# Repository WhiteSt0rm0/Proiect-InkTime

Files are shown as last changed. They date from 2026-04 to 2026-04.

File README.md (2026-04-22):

# Proiect InkTime

An affordable, open-source smartwatch powered by the nRF52840 with an e-paper display, designed for low power consumption and BLE connectivity.

## Table of Contents

1. [Hardware Diagram](#hardware-diagram)
2. [Bill of Materials](#bill-of-materials-bom)
3. [Hardware Description](#hardware-description)
4. [Pin Assignment](#nrf52840-pin-assignment)
5. [PCB Design Details](#pcb-design-details)

---

## Hardware Diagram

The InkTime smartwatch is built around the Nordic nRF52840 microcontroller and features the following subsystems:

```
                                    ┌───────────────────┐
                                    │    USB-C (J4)     │
                                    └──┬─────────────┬──┘
                                 VBUS  │             │ D+, D-
                                       │      ┌──────▼────────┐
                          ┌────────────┤      │  USBLC6 (D3)  │
                          │            │      │ ESD Protection│
                          │            │      └──────┬────────┘
                          │            │             │ D+, D- (protected)
                   ┌──────▼────────┐   │      ┌──────▼─────────────────────────┐
                   │  BQ25180 (IC3)│   │      │                                │
                   │  LiPo Charger │   │      │        nRF52840 (NRF52840_QF)  │
                   │  (I2C config) │   │      │        ARM Cortex-M4F @ 64MHz  │
                   └──────┬────────┘   │      │        BLE 5.0                 │
                          │            │      │                                │
                    VBAT  │     VBUS   │      │  ┌─────────────────────────┐   │
          ┌───────────────┤◄───────────┘      │  │ Interfaces:             │   │
          │               │                   │  │  SPI  → E-Paper Display │   │
   ┌──────▼────────┐      │                   │  │  I2C  → BMA423, DRV2605 │   │
   │ LiPo Battery  │      │                   │  │         MAX17048,       │   │
   │ LP502030      │      │                   │  │         BQ25180, RT6160 │   │
   │ 3.7V / 250mAh │      │                   │  │  USB  → USB-C (J4)      │   │
   └──────┬────────┘      │                   │  │  GPIO → Buttons, EPD    │   │
          │ VBAT          │                   │  │         ctrl, Haptic EN │   │
   ┌──────▼────────┐      │                   │  │  SWD  → TC2030 (J1)     │   │
   │ MAX17048 (U1) │──────│── I2C ───────────►│  └─────────────────────────┘   │
   │ Fuel Gauge    │      │                   │                                │
   │ (ALERT → GPIO)│      │                   │◄──── 32MHz Crystal (X1)        │
   └───────────────┘      │                   │◄──── 32.768kHz Crystal (X2)    │
                          │                   │◄──── 2.4GHz Antenna (ANT1)     │
                   ┌──────▼────────┐          │      via matching network      │
                   │  RT6160 (IC1) │          │      (L1, C3, C4, C9)          │
                   │  DC/DC        │          │                                │
                   │  Buck-Boost   │ VREG/3V3 │                                │
                   │  (I2C config) ├─────────►│                                │
                   └───────────────┘          └──┬──────┬──────┬───────────┬───┘
                                                 │      │      │           │
                              SPI (MOSI,SCK,CS)  │      │      │           │ GPIO
                              + GPIO ctrl        │      │ I2C  │ I2C       │ (SW_UP P0.26)
                                                 │      │      │           │ (SW_DN P0.27)
                  ┌──────────────────────┐       │      │      │       ┌───▼──────────────────┐
                  │  1.54" E-Paper (J2)  │◄──────┘      │      │       │  3×        Buttons   │
                  │  200×200px SPI       │              │      │       │  EVP-AKE31A          │
                  │                      │              │      │       │  (SW_ENT P1.00)      │
                  │  EPD Boost Circuit:  │              │      │       └──────────────────────┘
                  │  Q1 (DMG2305UX)      │              │      │
                  │  Q3 (SI1308EDL)      │       ┌──────▼──┐   │
                  │  D2,D4,D5 (MBR0530)  │       │ BMA423  │   │
                  │  L5 (68µH)           │       │  (IC2)  │   │
                  │  → PREVGH, PREVGL    │       │  IMU    │   │
                  └──────────────────────┘       └─────────┘   │
                                                        ┌──────▼──────┐
                           ┌──────────────┐             │  DRV2605    │
                           │  TC2030 (J1) │             │   (IC4)     │
                           │  SWD Debug   │             │  Haptic     │
                           │  (SWDIO,     │             │  Driver     │
                           │   SWDCLK,    │             │  + Motor    │
                           │   SWO, RST)  │             │  (FIT0774)  │
                           └──────────────┘             └─────────────┘
```

---

## Bill of Materials (BOM)

| Component | Value / Part Number | Package | Qty | Description | Datasheet |
|---|---|---|-----|---|---|
| NRF52840_QF | nRF52840 | QFN-73 | 1 | MCU with BLE 5.0 | [Link](datasheet-link) |
| IC1 | RT6160 | AWSCWL-CSP-15 | 1 | DC/DC Buck-Boost Converter | [Link](datasheet-link) |
| IC2 | BMA423 | LGA-12 | 1 | Triaxial Accelerometer (IMU) | [Link](datasheet-link) |
| IC3 | BQ25180 | YBGRDS-BGA-8 | 1 | LiPo Charger | [Link](datasheet-link) |
| IC4 | DRV2605 | YZFR-WCSP-9 | 1 | Haptic Driver | [Link](datasheet-link) |
| U1 | MAX17048 | G+T10-TDFN-8 | 1 | Fuel Gauge | [Link](datasheet-link) |
| D3 | USBLC6-2SC6Y | SOT-23-6 | 1 | ESD Protection | [Link](datasheet-link) |
| ANT1 | 2450AT18B100E | SMD | 1 | 2.4GHz Chip Antenna | [Link](datasheet-link) |
| X1 | 32MHz Crystal | SMD 2016 | 1 | Main Clock | - |
| X2 | 32.768kHz Crystal | SMD 3215 | 1 | RTC Clock | - |
| J1 | TC2030-IDC | Tag-Connect | 1 | SWD Debug Header | [Link](datasheet-link) |
| J2 | 503480-2400 | FPC-24 | 1 | E-Paper FPC Connector | [Link](datasheet-link) |
| J4 | KH-TYPE-C-16P | SMD | 1 | USB-C Connector | - |
| Q1 | DMG2305UX-7 | SOT-23 | 1 | P-Ch MOSFET (EPD drive) | [Link](datasheet-link) |
| Q3 | SI1308EDL-T1-GE3 | SC-70 | 1 | N-Ch MOSFET (EPD drive) | [Link](datasheet-link) |
| D2, D4, D5 | MBR0530 | SOD-123 | 3 | Schottky Diode (EPD drive) | - |
| L1 | 3.9nH | SMD 2012 | 1 | RF Matching Network | - |
| L2 | 10µH | SMD 2012 | 1 | nRF Power Inductor | - |
| L3 | 15nH | SMD 2012 | 1 | RF Filter | - |
| L5 | 68µH | SMD 2012 | 1 | EPD Boost Inductor | - |
| L7 | FTC252012SR47M-BCA | SMD 2012 | 1 | DC/DC Power Inductor (0.47µH) | - |
| SW_UP, SW_DN, SW_ENT | EVP-AKE31A | SMD | 3 | Tactile Buttons | - |
| SJ1 | Solder Jumper | SMD | 1 | Configuration Jumper | - |
| R1, R2, R5 | 0Ω | 0201 | 3 | Zero-ohm Resistors | - |
| R3, R4 | 3.3kΩ | 0201 | 2 | I2C Pull-up Resistors | - |
| R6, R2_EP_DR, R_PWR_EPD | 10kΩ | 0201 | 3 | Pull-up/Pull-down | - |
| R7, R8, R9 | 10kΩ | 0201 | 3 | Button Pull-down Resistors | - |
| R1_USB, R2_USB | 5.1kΩ | 0201 | 2 | USB-C CC Pull-down | - |
| R_TYPE_SEL | 2.2Ω | 0201 | 1 | EPD Type Select | - |
| R1_EP_DR | 0.47Ω | 0201 | 1 | EPD Current Sense | - |
| C1, C2, C17, C18 | 12pF | 0201 | 4 | Crystal Load Capacitors | - |
| C3, C4 | 1pF | 0201 | 2 | RF Matching | - |
| C9 | 820pF | 0201 | 1 | RF Matching | - |
| C5, C7, C8, C12, C19 | 100nF | 0201 | 5 | Decoupling Capacitors | - |
| C11 | 100pF | 0201 | 1 | Decoupling (DEC5) | - |
| C16 | 47nF | 0201 | 1 | Decoupling | - |
| C15 | 1.0µF | 0402 | 1 | Decoupling | - |
| C6, C14, C20, C21, C43, C2_EP_DR | 4.7µF | 0402 | 6 | Bulk Capacitors | - |
| C24, C39, C1_EP_DR | 10µF | 0402 | 3 | Input/Output Caps | - |
| C25, C33 | 22µF | 0402 | 2 | DC/DC Output Caps | - |
| C23, C27, C34, C42, EPD_C5 | 0.1µF | 0201 | 5 | Decoupling | - |
| C29-C32, C37, C38, EPD_C1-C12 | 1µF | 0402 | 15 | Filter/Bypass Caps | - |
| C10, C13, C22 | N.C. | 0201 | 3 | Do Not Populate | - |
| Test Pads | - | SMD | 14 | TP_GND, TP_3V3, TP_VBAT, etc. | - |

---

## Hardware Description

### Microcontroller — nRF52840 (NRF52840_QF)

The nRF52840 is the core of the InkTime, providing Bluetooth Low Energy 5.0 connectivity, ARM Cortex-M4F processing at 64MHz, and extensive GPIO. It communicates with peripherals via I2C and SPI buses and is powered by 3.3V from the RT6160 DC/DC converter.

Two crystals provide clock sources: a 32MHz crystal (X1) connected to XC1/XC2 with 12pF load capacitors (C1, C2), and a 32.768kHz crystal (X2) connected to P0.00/XL1 and P0.01/XL2 with 12pF load capacitors (C17, C18).

The RF section uses a 2450AT18B100E chip antenna connected through an impedance matching network (L1=3.9nH, C3=1pF, C4=1pF, C9=820pF) to the ANT pin. The antenna is placed at the edge of the PCB with a copper keepout zone on all layers underneath.

Decoupling capacitors placed close to corresponding power pins: C5 (100nF) on DEC1, C8 (100nF) on DEC3, C7 (100nF) on DEC4_6, C11 (100pF) on DEC5, C15 (1.0µF). Capacitors C10, C13, C22 are N.C. (Do Not Populate) per Nordic's reference design.

### Power Management

**LiPo Charger — BQ25180 (IC3):** Manages battery charging from USB-C (VBUS). Single-cell LiPo battery connected directly to test pads (TP_VBAT, TP_BAT_GND). I2C configurable. Interrupt output (PMIC_INT) to nRF52840. Bypass capacitors C37 (1µF), C39 (10µF). Pull-up R6 (10kΩ) on TS/MR.

**DC/DC Converter — RT6160 (IC1):** Buck-boost converter, VBAT (3.0–4.2V) to VREG/3V3. I2C voltage selection via VSEL pin. Power inductor L7 (0.47µH). Input cap C23 (0.1µF), output caps C24 (10µF), C25 (22µF), C33 (22µF). I2C pull-ups R3, R4 (3.3kΩ).

**Fuel Gauge — MAX17048 (U1):** Battery monitoring via I2C. CELL pin to VBAT, ALERT output to nRF52840. Bypass cap C38 (1µF).

### Display — 1.54" E-Paper

Connected via J2 (503480-2400). Uses an SPI interface (MOSI, SCK, EPD_CS). The drive circuit features Q3 (SI1308EDL), Q1 (DMG2305UX), diodes D2/D4/D5 (MBR0530), inductor L5 (68µH), and capacitors EPD_C1–C12 for high-voltage generation (PREVGH, PREVGL). Control signals include EPD_RST, EPD_BUSY, and EPD_DC.

### IMU — BMA423 (IC2)

Triaxial accelerometer connected via I2C (SDA, SCL). Provides two interrupt outputs (IMU_INT1, IMU_INT2) for motion/step/gesture detection. Features a decoupling C19 (100nF) and zero-ohm resistors R1, R2, R5 for pin configuration.

### Haptic Driver — DRV2605 (IC4)

I2C haptic driver for the vibration motor (FIT0774). Enabled via the HAPTIC_EN GPIO pin. Includes decoupling capacitors C32 (1µF) and C34 (0.1µF).

### USB-C and ESD Protection

Features a KH-TYPE-C-16P connector (J4) with USBLC6-2SC6Y (D3) for ESD protection. Includes CC pull-downs R1_USB, R2_USB (5.1kΩ) and bypass caps C42 (0.1µF), C43 (4.7µF).

### SWD Debug — TC2030-IDC (J1)

Utilizes a Tag-Connect pogo-pin interface: SWDIO, SWDCLK, SWO, RESET, 3.3V, GND. This allows for debugging without requiring a permanent connector on the board.

---

## nRF52840 Pin Assignment

| Pin | Signal | Function | Interface |
|-----|---|---|---|
| P0.00/XL1 | XL1 | 32.768kHz Crystal | Clock |
| P0.01/XL2 | XL2 | 32.768kHz Crystal | Clock |
| P0.04/AIN2 | IMU_INT1 | BMA423 Interrupt 1 | GPIO |
| P0.05/AIN3 | IMU_INT2 | BMA423 Interrupt 2 | GPIO |
| P0.06 | EPD_CS | E-Paper Chip Select | SPI |
| P0.07 | EPD_DC | E-Paper Data/Command | GPIO |
| P0.08 | EPD_RST | E-Paper Reset | GPIO |
| P0.09/NFC1 | PMIC_INT | BQ25180 Interrupt | GPIO |
| P0.11 | SCK | SPI Clock (E-Paper) | SPI |
| P0.12 | MOSI | SPI Data (E-Paper) | SPI |
| P0.13 | EPD_BUSY | E-Paper Busy | GPIO |
| P0.14 | SCL | I2C Clock | I2C |
| P0.15 | SDA | I2C Data | I2C |
| P0.18/RESET | RESET | System Reset | Reset |
| P0.19 | HAPTIC_EN | DRV2605 Enable | GPIO |
| P0.26 | SW_UP | Button Up | GPIO |
| P0.27 | SW_DN | Button Down | GPIO |
| P1.00 | SW_ENT | Button Enter | GPIO |
| P1.01 | ALERT | MAX17048 Alert | GPIO |
| P1.09 | SWO | Debug Trace Output | Debug |
| XC1/XC2 | Crystal | 32MHz Oscillator | Clock |
| ANT | RF | Antenna via matching | RF |
| VBUS | USB_VBUS | USB Power (5V) | Power |
| D+/D- | USB Data | USB Data Lines | USB |
| SWDIO | Debug | SWD Data | Debug |
| SWDCLK | Debug | SWD Clock | Debug |

**Note:** The I2C Bus is shared by BMA423 (IC2), BQ25180 (IC3), RT6160 (IC1), DRV2605 (IC4), and MAX17048 (U1). It uses pull-ups R3, R4 (3.3kΩ) to 3V3.

---

## PCB Design Details

### Board Specifications

- **Dimensions:** 46mm × 35mm, rounded corners
- **Layers:** 4 (Top, Route2, Route63, Bottom)
- **Thickness:** 1.0mm
- **Trace widths:** 0.15mm (signals), 0.3mm (power)
- **Components:** All mounted on the TOP layer

### Layer Stack

| Layer | Name | Function |
|---|---|---|
| 1 | Top | Signals + GND polygon |
| 2 | Route2 | Dedicated GND plane |
| 6 | Route63 | Signal routing |
| 4 | Bottom | Signals + GND polygon |

### Design Decisions and Accepted Errors

**Copper Width Errors:** Power nets (3V3, VREG, VBAT, VBUS, etc.) require 0.3mm trace width per design rules. However, in dense areas—particularly around small IC packages and tight pad spacing—there is not enough physical space to maintain this width. These resulting DRC errors were manually verified and accepted.

**Copper Clearance Errors:** In highly congested areas (around the nRF52840 BGA and passive component clusters), some traces and pads violate the 0.15mm clearance rule. These occur where component placement leaves no alternative routing path and were accepted after confirming no actual shorts exist.

**Overlapping / Polygon Clearance Errors:** Some GND polygons on different layers generate clearance warnings where they overlap. These are non-functional warnings, as the polygons belong to the same net (GND).

**Board Outline Clearance Errors:** The three tactile buttons (SW_UP, SW_DN, SW_ENT) and the USB-C connector (J4) intentionally extend beyond the PCB edge for mechanical alignment with the enclosure cutouts. This is by design.

**N.C. Capacitors:** Footprints (C10, C13, C22) are present but intentionally not populated per Nordic's reference design.

**Silkscreen:** Proper labeling is applied to ICs, connectors, test pads, and capacitors.

**Via Stitching:** GND vias are distributed across the board between all ground planes, with a higher concentration around the nRF52840 and RF antenna area to ensure low-impedance ground return paths at 2.4GHz.

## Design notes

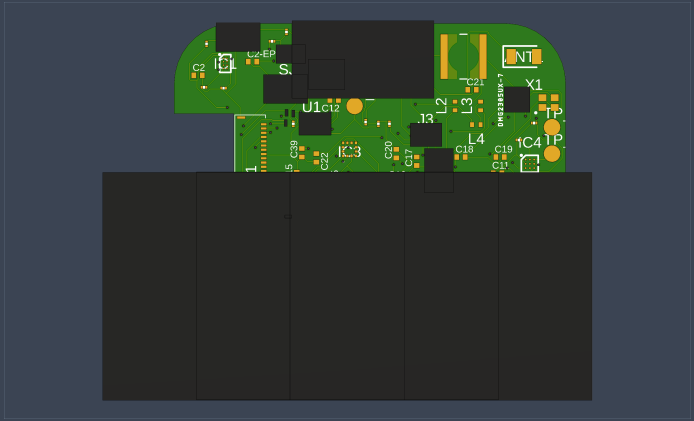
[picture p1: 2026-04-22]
Images/Screenshot 2026-04-22 132725.png

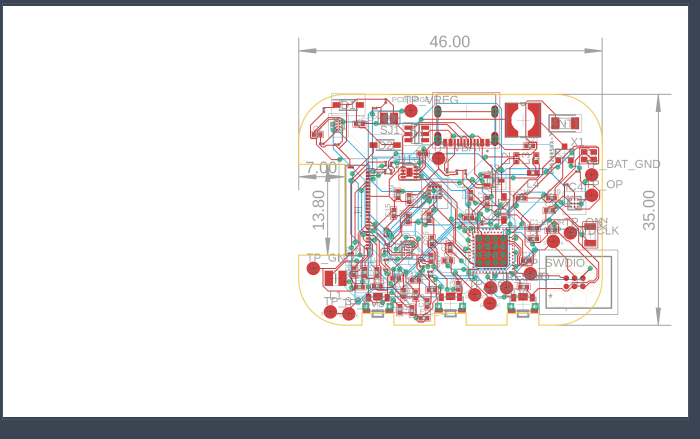
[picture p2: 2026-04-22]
Images/Screenshot 2026-04-22 132748.png

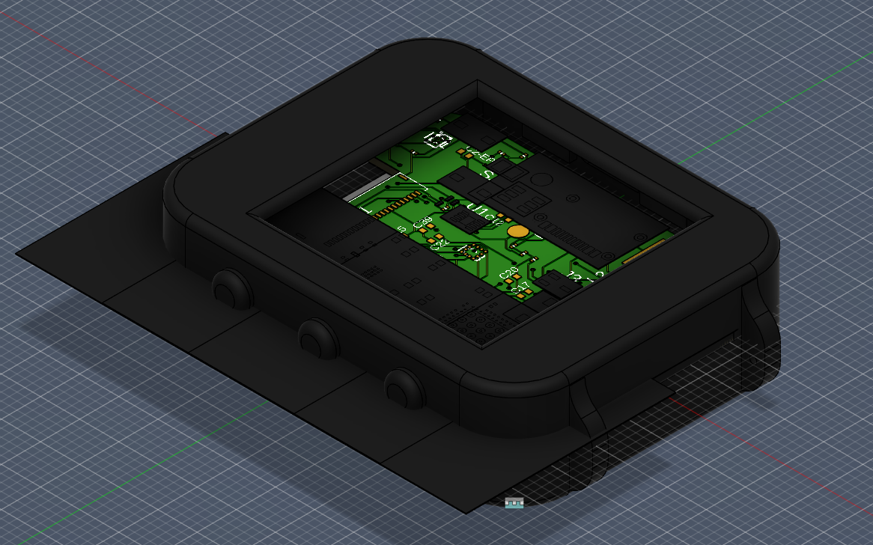
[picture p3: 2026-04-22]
Images/Screenshot 2026-04-22 132715.png

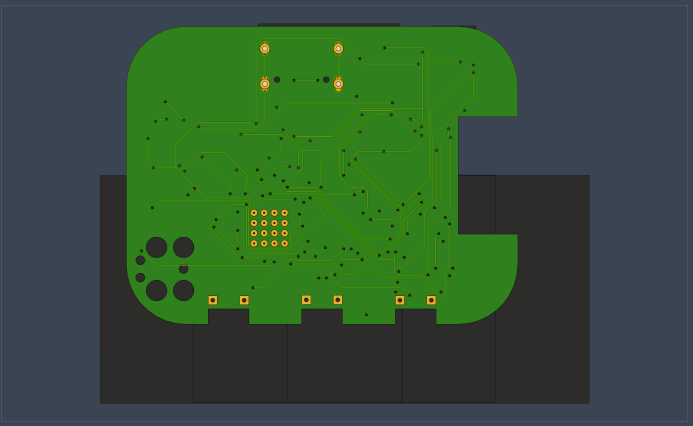
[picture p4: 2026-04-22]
Images/Screenshot 2026-04-22 132744.png

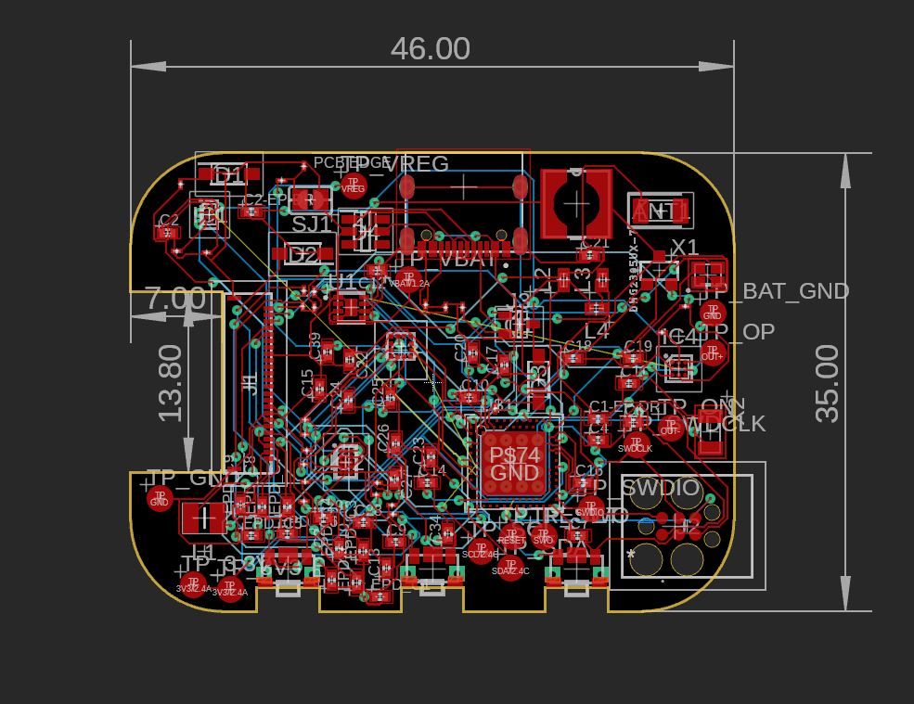
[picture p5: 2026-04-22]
Images/Screenshot 2026-04-22 132706.png

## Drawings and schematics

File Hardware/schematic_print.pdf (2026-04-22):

# LiPo Charger

# DC/DC

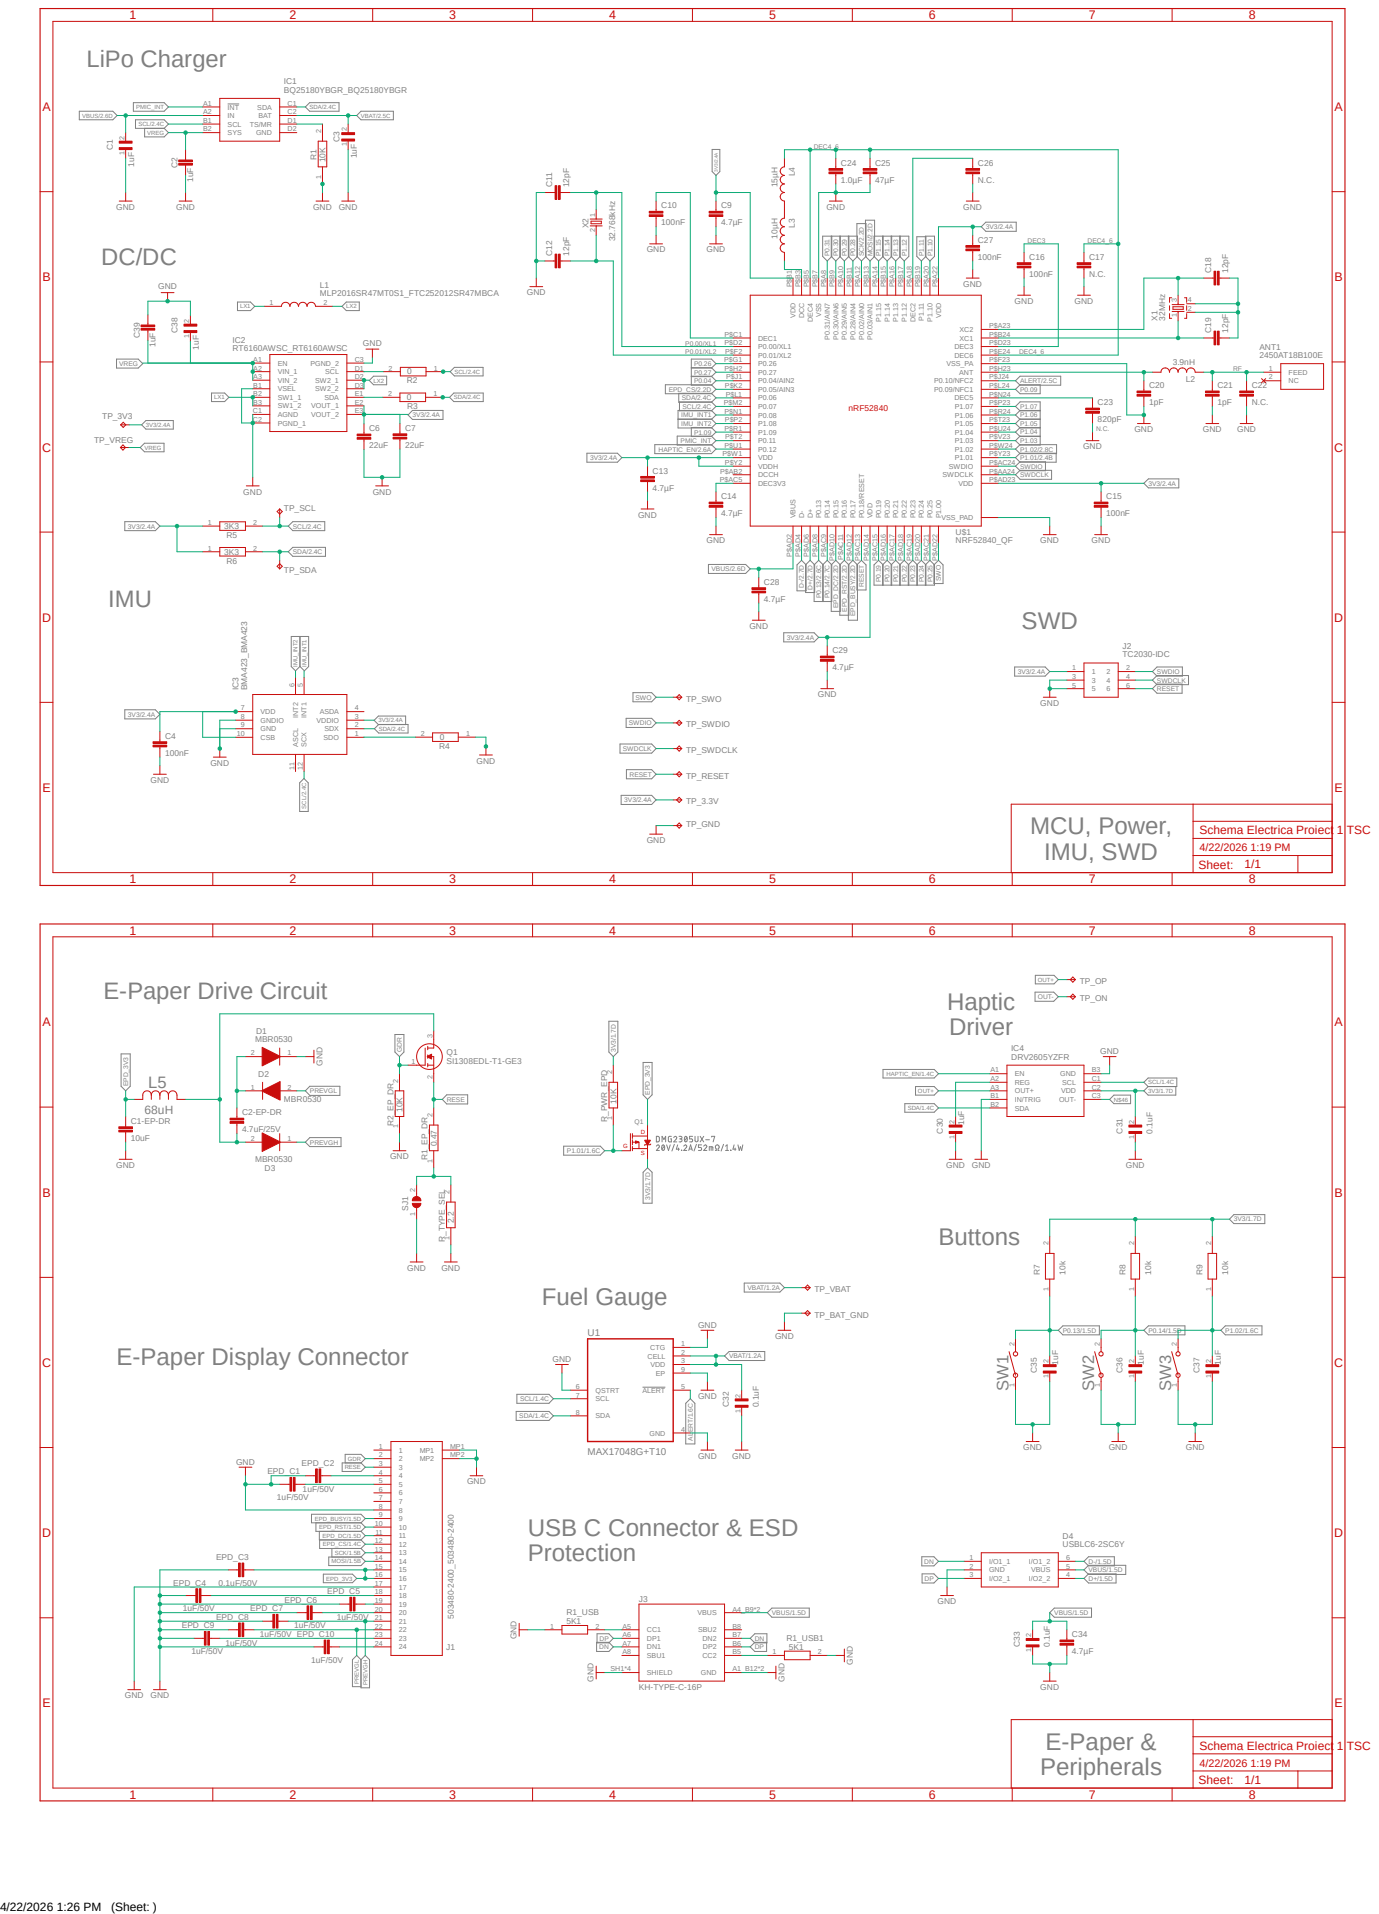
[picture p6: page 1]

MCU, Power, IMU, SWD

Schema Electrica Proiect 1 TSC

Sheet: 1/1

EPD_C5 | 18 18

EPD_C6 | 19 19

EPD_C8 | 1uF/50V | 21 21

EPD_C9 | 1uF/50V | | 22 22

E-Paper & Peripherals

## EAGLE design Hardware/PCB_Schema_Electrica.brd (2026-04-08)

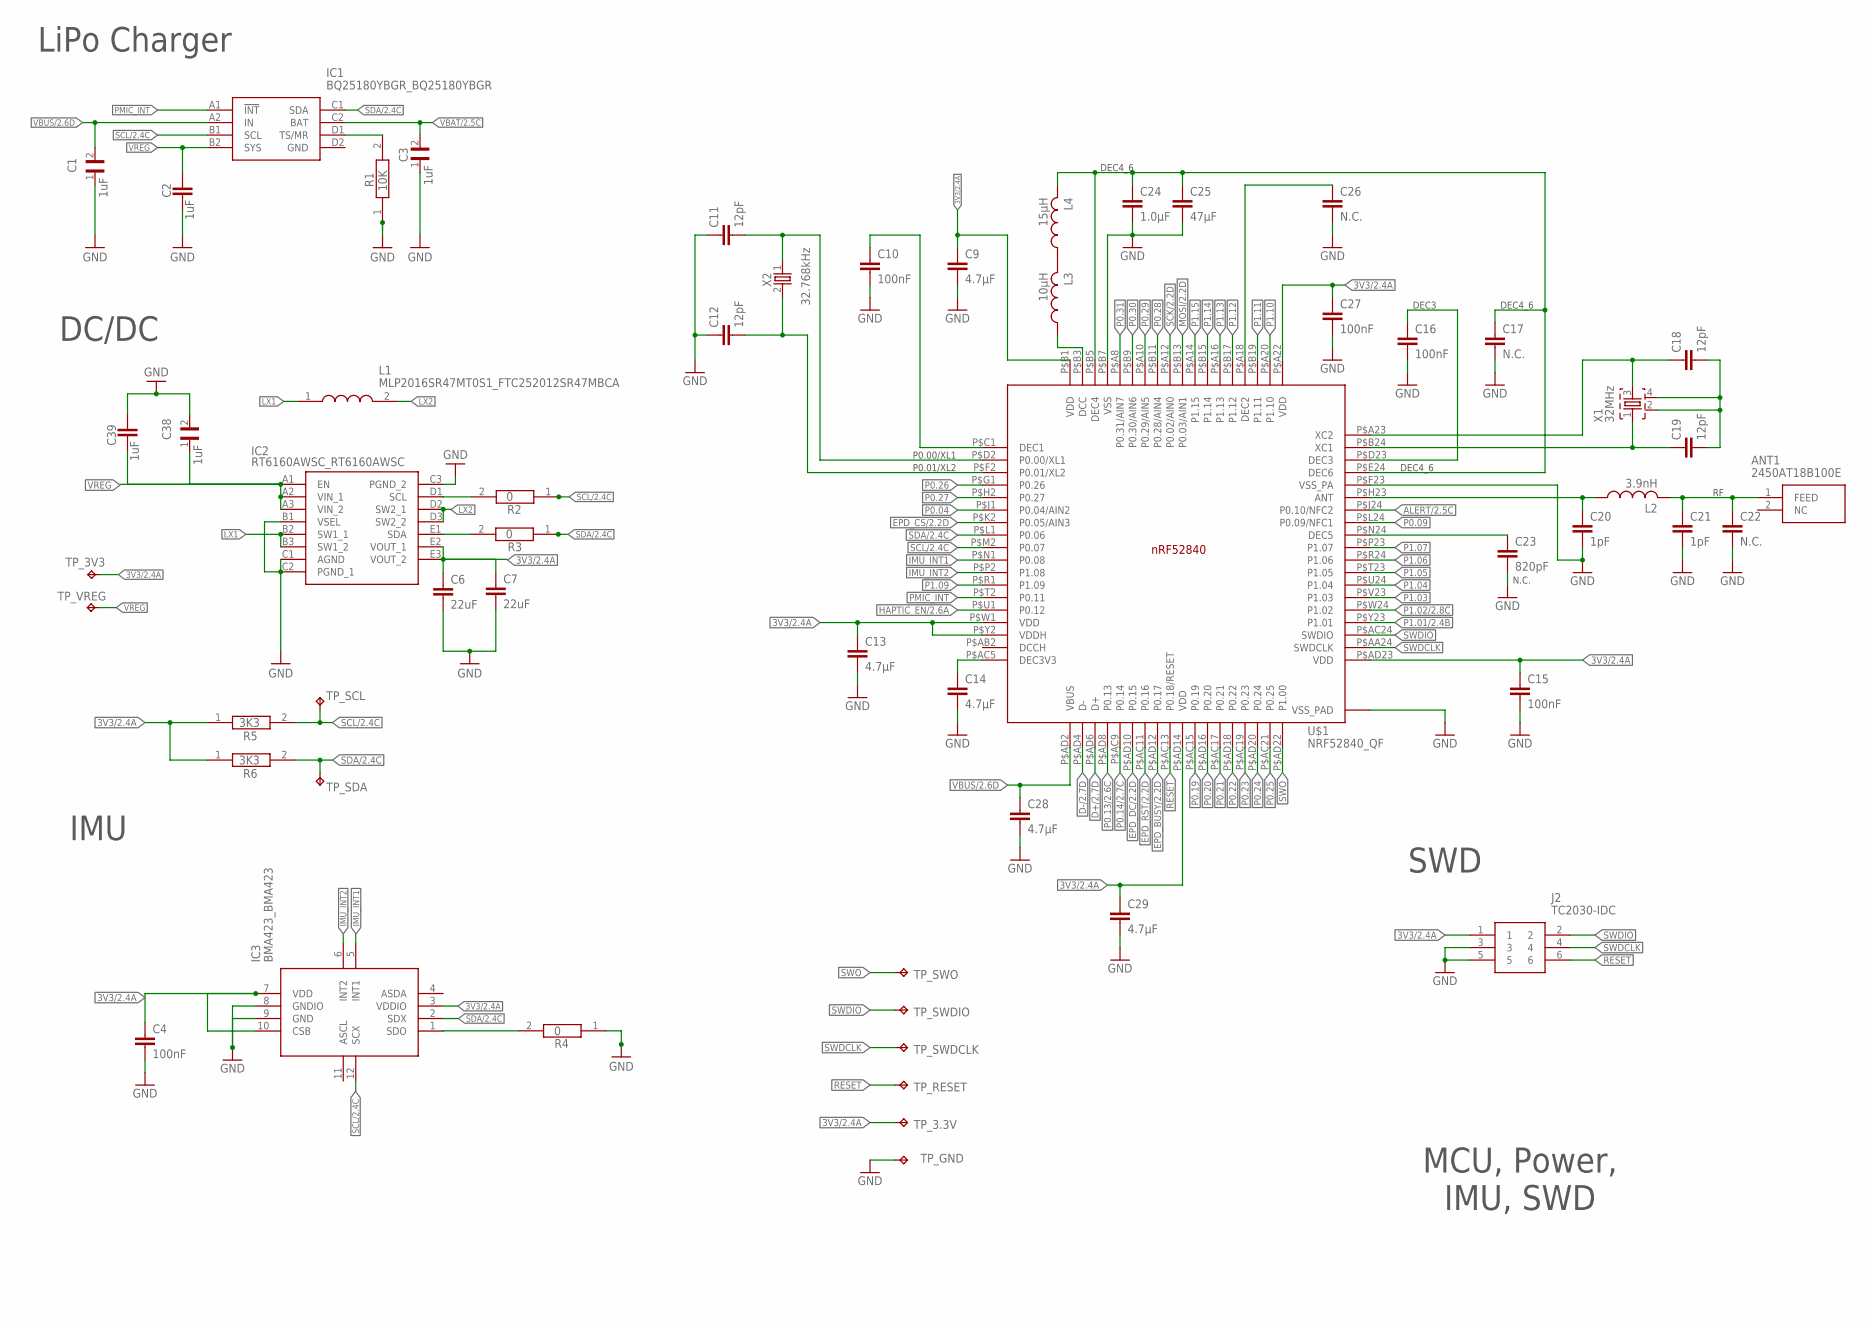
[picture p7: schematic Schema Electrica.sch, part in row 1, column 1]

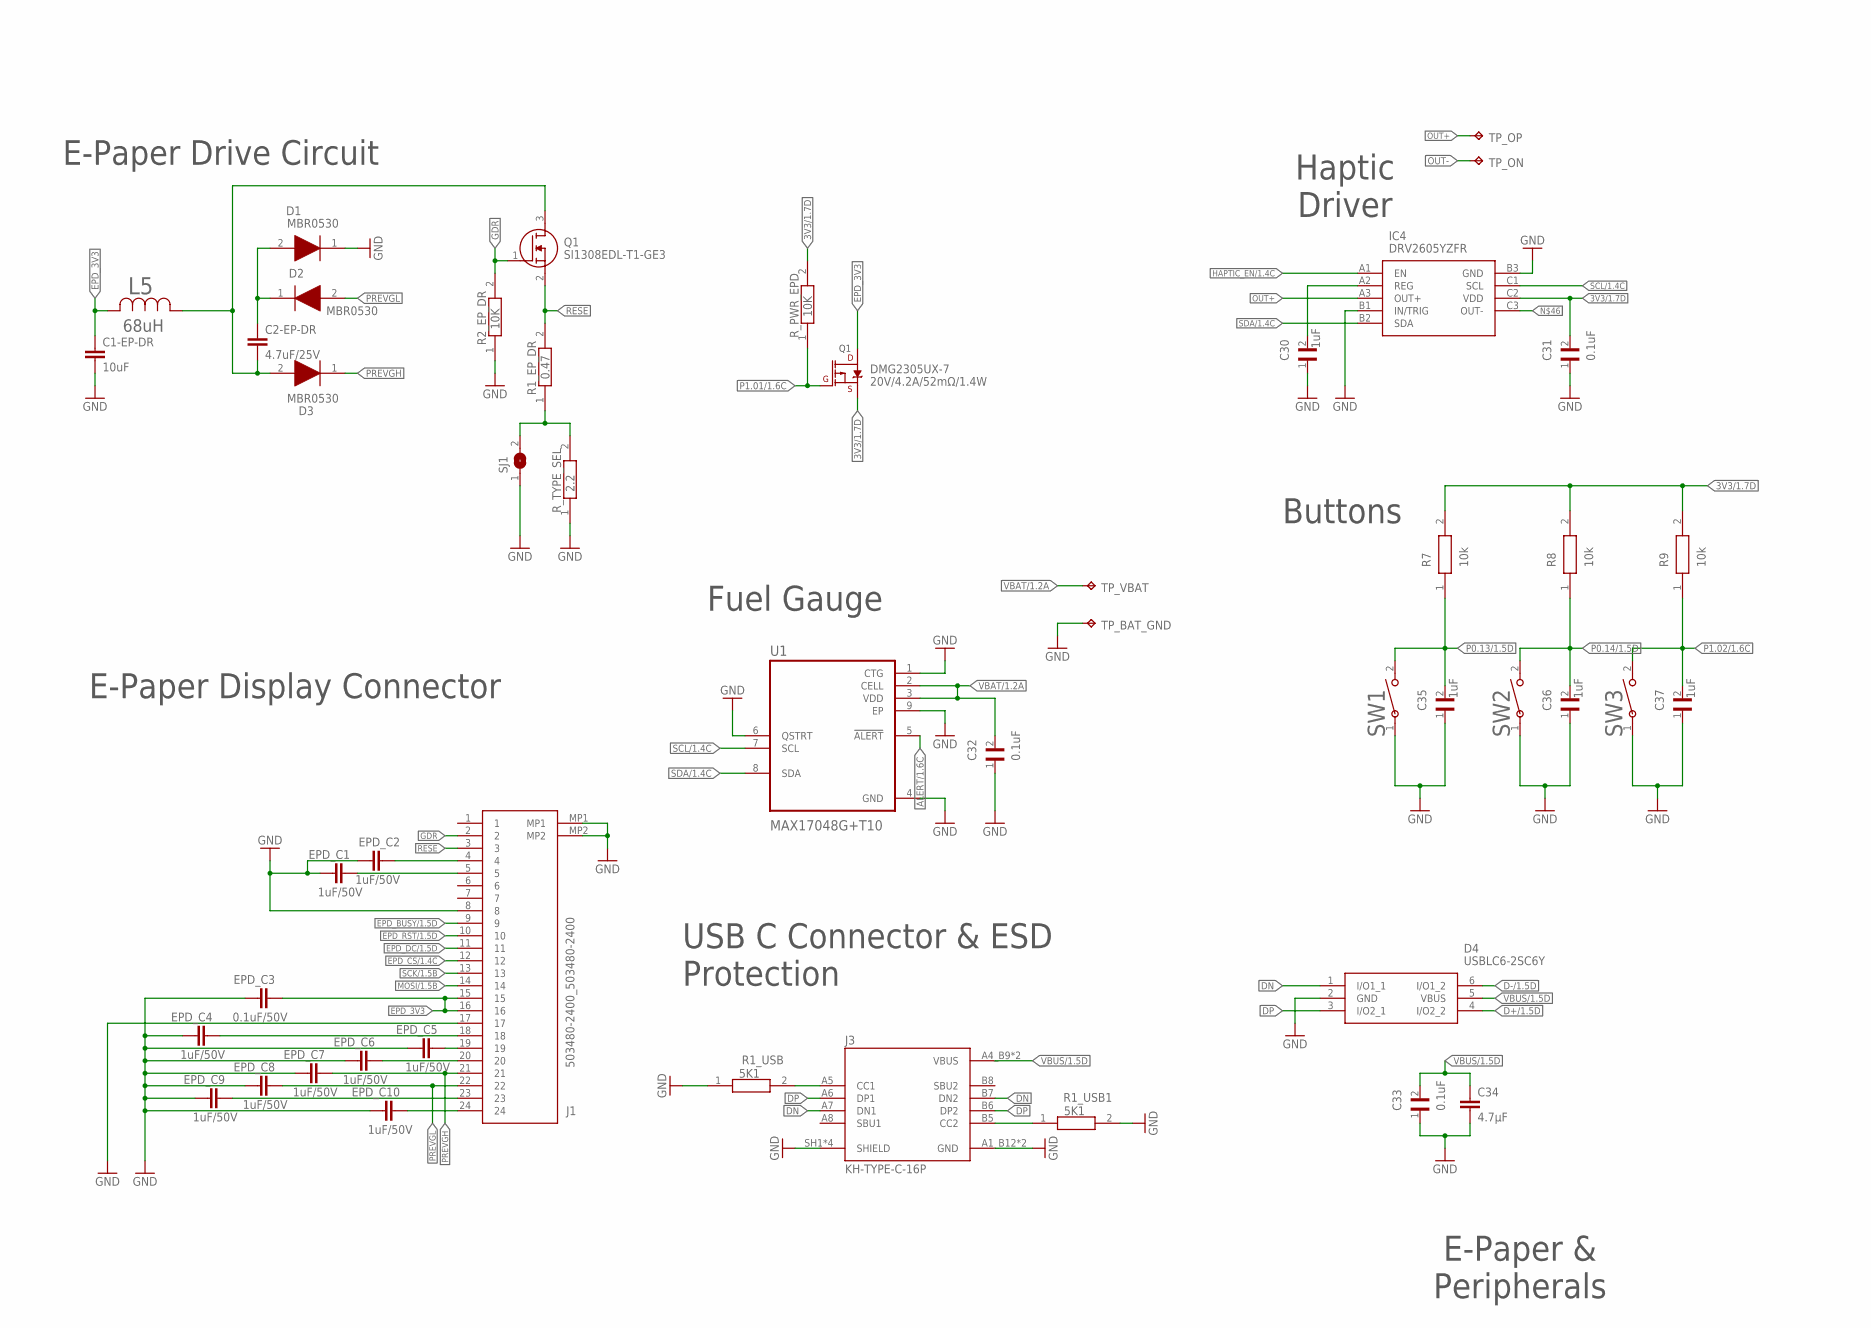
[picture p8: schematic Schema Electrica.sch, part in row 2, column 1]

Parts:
ANT1: 2450AT18B100E; 2450AT18B100E_ANTC3216X140N
C1, C3, C30, C35, C36, C37, C38: 1uF; GRM011R60J152KE01L_1_0201
C1-EP-DR: 10uF; PERFECT_0402_0402
C2, C39: 1uF; PERFECT_0402_0402
C2-EP-DR: 4.7uF/25V; PERFECT_0402_0402
C4, C10, C15, C16, C27: 100nF; PERFECT_0402_0402
C6, C7: 22uF; PERFECT_0402_0402
C9, C13, C14, C28, C29, C34: 4.7µF; PERFECT_0402_0402
C11, C12, C18, C19: 12pF; PERFECT_0402_0402
C17, C22, C26: N.C.; PERFECT_0402_0402
C20, C21: 1pF; PERFECT_0402_0402
C23: 820pF; PERFECT_0402_0402
C24: 1.0µF; PERFECT_0402_0402
C25: 47µF; PERFECT_0402_0402
C31, C32, C33: 0.1uF; GRM011R60J152KE01L_1_0201
D1, D2, D3: MBR0530; ESP32_C6_LIBRARY_5_SOD3716X135N
D4: USBLC6-2SC6Y; ESP32_C6_LIBRARY_3_SOT95P280X145-6N
DMG2305UX-7: 20V/4.2A/52mΩ/1.4W; ESP32_C6_LIBRARY_4_ESP32_C6_LIBRARY_4_ESP32_C6_LIBRARY_4_ES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
EPD_C1, EPD_C2, EPD_C4, EPD_C5, EPD_C6, EPD_C7, EPD_C8, EPD_C9, EPD_C10: 1uF/50V; PERFECT_0402_0402
EPD_C3: 0.1uF/50V; PERFECT_0402_0402
IC1: BQ25180YBGR_BQ25180YBGR; BQ25180YBGR_BGA8C40P2X4_100X155X50
IC2: RT6160AWSC_RT6160AWSC; RT6160AWSC_BGA15C40P3X5_140X230X60
IC3: BMA423_BMA423
IC4: DRV2605YZFR; DRV2605YZFR_BGA9C50P3X3_144X144X62
J1: 503480-2400_503480-2400; 503480-2400_5034802400
J2: TC2030-IDC; TC2030-IDC_TC2030IDC
J3: KH-TYPE-C-16P; KH-TYPE-C-16P_KINGHELM_KH-TYPE-C-16P
L1: MLP2016SR47MT0S1_FTC252012SR47MBCA; MLP2016SR47MT0S1_INDC2016X100N
L2: 3.9nH; NORDIC_NRF_2_RESC0402_L
L3: 10µH; NORDIC_NRF_2_RESC0402_L
L4: 15µH; NORDIC_NRF_2_RESC0402_L
L5: 68uH; ESP32_C6_LIBRARY_2_IND_4828-WE-TPC_WRE
Q1: SI1308EDL-T1-GE3; ESP32_C6_LIBRARY_6_SOT65P210X110-3N
R1, R2_EP_DR: 10K; CPF0201D7K68C1_0201
R1_EP_DR: 0.47; CPF0201D7K68C1_0201
R1_USB, R1_USB1: 5K1; CPF0201D7K68C1_0201
R2, R3: 0; CPF0201D7K68C1_0201
R4: 0; ERA-1AEB3401C_0201
R5, R6: 3K3; CPF0201D7K68C1_0201
R7, R8, R9: 10k; ERA-1AEB3401C_0201
R_PWR_EPD: 10K; CPF0201D7K68C1_0201
R_TYPE_SEL: 2.2; CPF0201D7K68C1_0201
SJ1: ESP32_C6_LIBRARY_7_JUMPER_SJ
SW1, SW2, SW3: 2025-10-22_07-23-44_LIBRARY_EVP-AKE31ASW_EVP-AKE3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; 2025-10-22_07-23-44_LIBRARY_SW_EVP-AKE31A_PAN
TP_3.3V, TP_3V3: HECTOR_WATCH_1_TPTP20R; HECTOR_WATCH_1_TP20R
TP_BAT_GND: HECTOR_WATCH_1_TPTP20R; HECTOR_WATCH_1_TP20R
TP_GND: HECTOR_WATCH_1_TPTP20R; HECTOR_WATCH_1_TP20R
TP_ON: HECTOR_WATCH_1_TPTP20R; HECTOR_WATCH_1_TP20R
TP_OP: HECTOR_WATCH_1_TPTP20R; HECTOR_WATCH_1_TP20R
TP_RESET: HECTOR_WATCH_1_TPTP20R; HECTOR_WATCH_1_TP20R
TP_SCL: HECTOR_WATCH_1_TPTP20R; HECTOR_WATCH_1_TP20R
TP_SDA: HECTOR_WATCH_1_TPTP20R; HECTOR_WATCH_1_TP20R
TP_SWDCLK: HECTOR_WATCH_1_TPTP20R; HECTOR_WATCH_1_TP20R
TP_SWDIO: HECTOR_WATCH_1_TPTP20R; HECTOR_WATCH_1_TP20R
TP_SWO: HECTOR_WATCH_1_TPTP20R; HECTOR_WATCH_1_TP20R
TP_VBAT: HECTOR_WATCH_1_TPTP20R; HECTOR_WATCH_1_TP20R
TP_VREG: HECTOR_WATCH_1_TPTP20R; HECTOR_WATCH_1_TP20R
U1: MAX17048G+T10; ESP32_C6_LIBRARY_SON50P200X200X80-9N
U$1: NRF52840_QF; NORDIC_NRF_4_AQFN50P700X700X85_HS-74N
X1: 32MHz; NORDIC_NRF_BT-XTAL_2016_N
X2: 32.768kHz; NORDIC_NRF_1_XTAL_3215_N

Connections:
3V3/1.7D: C31.2, DMG2305UX-7.2 (S), IC4.C2 (VDD), R7.2, R8.2, R9.2, R_PWR_EPD.2
3V3/2.4A: C4.1, C6.1, C7.1, C9.1, C13.1, C15.1, C27.1, C29.1, IC2.E2 (VOUT_1), IC2.E3 (VOUT_2), IC3.3 (VDDIO), IC3.7 (VDD), IC3.10 (CSB), J2.1, R5.1, R6.1, TP_3.3V.TP, TP_3V3.TP, U$1.P$A22 (VDD), U$1.P$AD14 (VDD), U$1.P$AD23 (VDD), U$1.P$B1 (VDD), U$1.P$W1 (VDD), U$1.P$Y2 (VDDH)
ALERT/1.6C: U1.5 (!ALERT)
ALERT/2.5C: U$1.P$J24 (P0.10/NFC2)
D+/1.5D: D4.4 (I/O2_2)
D+/2.7D: U$1.P$AD6 (D+)
D-/1.5D: D4.6 (I/O1_2)
D-/2.7D: U$1.P$AD4 (D-)
DEC3: C16.1, U$1.P$D23 (DEC3)
DN: D4.1 (I/O1_1), J3.A7 (DN1), J3.B7 (DN2)
DP: D4.3 (I/O2_1), J3.A6 (DP1), J3.B6 (DP2)
EPD_3V3: C1-EP-DR.1, DMG2305UX-7.3 (D), EPD_C3.2, J1.15, J1.16, L5.2
EPD_BUSY/1.5D: J1.9
EPD_BUSY/2.2D: U$1.P$AD12 (P0.17)
EPD_CS/1.4C: J1.12
EPD_CS/2.2D: U$1.P$K2 (P0.05/AIN3)
EPD_DC/1.5D: J1.11
EPD_DC/2.2D: U$1.P$AD10 (P0.15)
EPD_RST/1.5D: J1.10
EPD_RST/2.2D: U$1.P$AC11 (P0.16)
GDR: J1.2, Q1.1 (G), R2_EP_DR.2
GND: C1.1, C1-EP-DR.2, C2.2, C3.1, C4.2, C6.2, C7.2, C9.2, C10.2, C11.1, C12.1, C13.2, C14.2, C15.2, C16.2, C17.2, C20.2, C21.2, C22.2, C23.2, C24.2, C25.2, C26.2, C27.2, C28.2, C29.2, C30.1, C31.1, C32.1, C33.1, C34.2, C35.1, C36.1, C37.1, C38.2, C39.1, D1.1 (K), D4.2 (GND), EPD_C1.1, EPD_C2.1, EPD_C3.1, EPD_C4.1, EPD_C5.1, EPD_C6.1, EPD_C7.1, EPD_C8.1, EPD_C9.1, EPD_C10.1, IC3.8 (GNDIO), IC3.9 (GND), IC4.B1 (IN/TRIG), IC4.B3 (GND), J1.8, J1.17, J1.MP1, J1.MP2, J2.3, J2.5, J3.A1_B12 (GND), J3.A12_B1 (GND), J3.SH1 (SHIELD), J3.SH2 (SHIELD), J3.SH3 (SHIELD), J3.SH4 (SHIELD), R1.1, R1_USB.1, R1_USB1.2, R2_EP_DR.1, R4.1, R_TYPE_SEL.1, SJ1.1, SW1.1, SW2.1, SW3.1, TP_BAT_GND.TP, TP_GND.TP, U1.1 (CTG), U1.4 (GND), U1.6 (QSTRT), U1.9 (EP), U$1.P$74 (VSS_PAD), U$1.P$75 (VSS_PAD), U$1.P$76 (VSS_PAD), U$1.P$77 (VSS_PAD), U$1.P$78 (VSS_PAD), U$1.P$79 (VSS_PAD), U$1.P$80 (VSS_PAD), U$1.P$81 (VSS_PAD), U$1.P$82 (VSS_PAD), U$1.P$83 (VSS_PAD), U$1.P$84 (VSS_PAD), U$1.P$85 (VSS_PAD), U$1.P$86 (VSS_PAD), U$1.P$87 (VSS_PAD), U$1.P$88 (VSS_PAD), U$1.P$89 (VSS_PAD), U$1.P$90 (VSS_PAD), U$1.P$B7 (VSS), U$1.P$F23 (VSS_PA)
HAPTIC_EN/1.4C: IC4.A1 (EN)
HAPTIC_EN/2.6A: U$1.P$U1 (P0.12)
IMU_INT1: IC3.5 (INT1), U$1.P$N1 (P0.08)
IMU_INT2: IC3.6 (INT2), U$1.P$P2 (P1.08)
LX1: IC2.B2 (SW1_1), IC2.B3 (SW1_2), L1.1
LX2: IC2.D2 (SW2_1), IC2.D3 (SW2_2), L1.2
MOSI/1.5B: J1.14
MOSI/2.2D: U$1.P$B13 (P0.03/AIN1)
unnamed: IC1.D1 (TS/MR), R1.2
unnamed: IC2.D1 (SCL), R2.2
unnamed: IC2.E1 (SDA), R3.2
unnamed: IC3.1 (SDO), R4.2
unnamed: IC2.B1 (VSEL), IC2.C1 (AGND), IC2.C2 (PGND_1)
unnamed: C10.1, U$1.P$C1 (DEC1)
unnamed: C11.2, U$1.P$D2 (P0.00/XL1), X2.1
unnamed: C12.2, U$1.P$F2 (P0.01/XL2), X2.2
unnamed: C14.1, U$1.P$AC5 (DEC3V3)
unnamed: C17.1, C24.1, C25.1, L4.2, U$1.P$B5 (DEC4), U$1.P$E24 (DEC6)
unnamed: C18.1, U$1.P$A23 (XC2), X1.3
unnamed: C18.2, C19.2, X1.2, X1.4
unnamed: C19.1, U$1.P$B24 (XC1), X1.1
unnamed: C20.1, L2.1, U$1.P$H23 (ANT)
unnamed: ANT1.1 (FEED), C21.1, C22.1, L2.2
unnamed: C23.1, U$1.P$N24 (DEC5)
unnamed: L3.1, U$1.P$B3 (DCC)
unnamed: C26.1, U$1.P$A18 (DEC2)
unnamed: L3.2, L4.1
unnamed: C2-EP-DR.1, D1.2 (A), D2.1 (K)
unnamed: C2-EP-DR.2, D3.2 (A), L5.1, Q1.3 (D)
unnamed: EPD_C2.2, J1.4
unnamed: EPD_C1.2, J1.5
unnamed: EPD_C4.2, J1.18
unnamed: EPD_C5.2, J1.19
unnamed: EPD_C6.2, J1.20
unnamed: J3.A5 (CC1), R1_USB.2
unnamed: R1_EP_DR.1, R_TYPE_SEL.2, SJ1.2
unnamed: EPD_C9.2, J1.23
unnamed: EPD_C10.2, J1.24
unnamed: C30.2, IC4.A2 (REG)
unnamed: J3.B5 (CC2), R1_USB1.1
OUT+: IC4.A3 (OUT+), TP_OP.TP
OUT-: TP_ON.TP
P0.04: U$1.P$J1 (P0.04/AIN2)
P0.09: U$1.P$L24 (P0.09/NFC1)
P0.13/1.5D: C35.2, R7.1, SW1.2
P0.13/2.6C: U$1.P$AD8 (P0.13)
P0.14/1.5D: C36.2, R8.1, SW2.2
P0.14/2.7C: U$1.P$AC9 (P0.14)
P0.19: U$1.P$AC15 (P0.19)
P0.20: U$1.P$AD16 (P0.20)
P0.21: U$1.P$AC17 (P0.21)
P0.22: U$1.P$AD18 (P0.22)
P0.23: U$1.P$AC19 (P0.23)
P0.24: U$1.P$AD20 (P0.24)
P0.25: U$1.P$AC21 (P0.25)
P0.26: U$1.P$G1 (P0.26)
P0.27: U$1.P$H2 (P0.27)
P0.28: U$1.P$B11 (P0.28/AIN4)
P0.29: U$1.P$A10 (P0.29/AIN5)
P0.30: U$1.P$B9 (P0.30/AIN6)
P0.31: U$1.P$A8 (P0.31/AIN7)
P1.01/1.6C: DMG2305UX-7.1 (G), R_PWR_EPD.1
P1.01/2.4B: U$1.P$Y23 (P1.01)
P1.02/1.6C: C37.2, R9.1, SW3.2
P1.02/2.8C: U$1.P$W24 (P1.02)
P1.03: U$1.P$V23 (P1.03)
P1.04: U$1.P$U24 (P1.04)
P1.05: U$1.P$T23 (P1.05)
P1.06: U$1.P$R24 (P1.06)
P1.07: U$1.P$P23 (P1.07)
P1.09: U$1.P$R1 (P1.09)
P1.10: U$1.P$A20 (P1.10)
P1.11: U$1.P$B19 (P1.11)
P1.12: U$1.P$B17 (P1.12)
P1.13: U$1.P$A16 (P1.13)
P1.14: U$1.P$B15 (P1.14)
P1.15: U$1.P$A14 (P1.15)
PMIC_INT: IC1.A1 (!INT), U$1.P$T2 (P0.11)
PREVGH: D3.1 (K), EPD_C7.2, J1.21
PREVGL: D2.2 (A), EPD_C8.2, J1.22
RESE: J1.3, Q1.2 (S), R1_EP_DR.2
RESET: J2.6, TP_RESET.TP, U$1.P$AC13 (P0.18/RESET)
SCK/1.5B: J1.13
SCK/2.2D: U$1.P$A12 (P0.02/AIN0)
SCL/1.4C: IC4.C1 (SCL), U1.7 (SCL)
SCL/2.4C: IC1.B1 (SCL), IC3.12 (SCX), R2.1, R5.2, TP_SCL.TP, U$1.P$M2 (P0.07)
SDA/1.4C: IC4.B2 (SDA), U1.8 (SDA)
SDA/2.4C: IC1.C1 (SDA), IC3.2 (SDX), R3.1, R6.2, TP_SDA.TP, U$1.P$L1 (P0.06)
SWDCLK: J2.4, TP_SWDCLK.TP, U$1.P$AA24 (SWDCLK)
SWDIO: J2.2, TP_SWDIO.TP, U$1.P$AC24 (SWDIO)
SWO: TP_SWO.TP, U$1.P$AD22 (P1.00)
VBAT/1.2A: C32.2, TP_VBAT.TP, U1.2 (CELL), U1.3 (VDD)
VBAT/2.5C: C3.2, IC1.C2 (BAT)
VBUS/1.5D: C33.2, C34.1, D4.5 (VBUS), J3.A4_B9 (VBUS), J3.A9_B4 (VBUS)
VBUS/2.6D: C1.2, C28.1, IC1.A2 (IN), U$1.P$AD2 (VBUS)
VREG: C2.1, C38.1, C39.2, IC1.B2 (SYS), IC2.A1 (EN), IC2.A2 (VIN_1), IC2.A3 (VIN_2), TP_VREG.TP

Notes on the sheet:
LiPo Charger
DC/DC
IMU
P0.00/XL1
P0.01/XL2
DEC3
DEC4_6
N.C.
E-Paper Drive Circuit
E-Paper Display Connector
Haptic Driver
Fuel Gauge
SWD
USB C Connector & ESD Protection
Buttons
MCU, Power, IMU, SWD
E-Paper & Peripherals

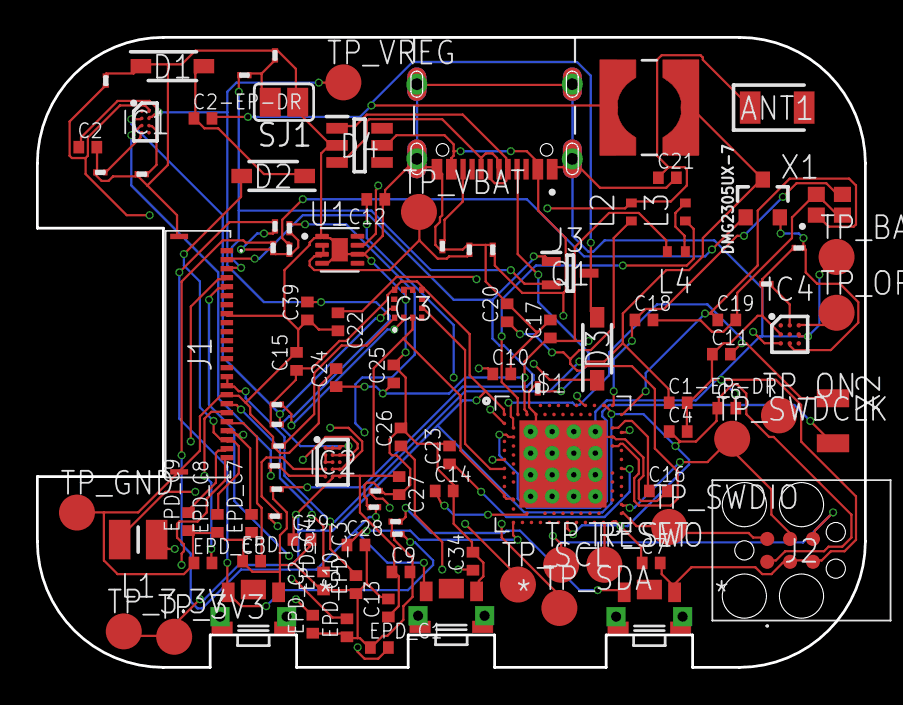
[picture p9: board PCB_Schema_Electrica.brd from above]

Board: 4 copper layers, 46.0 x 35.0 mm, 105 parts (0 on the bottom side), 66 nets.

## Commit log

2026-04-08 commit 1, incomplete tasks
    [PCB_Schema_Electrica.brd, Schema Electrica.sch]
2026-04-22 Expand README with hardware details and design choices
    Added detailed hardware specifications, including diagrams, bill of materials, and design decisions for the InkTime smartwatch project.
2026-04-22 Revise README format and content
    Updated the README to improve structure and clarity, added a table of contents, and reformatted the Bill of Materials section.

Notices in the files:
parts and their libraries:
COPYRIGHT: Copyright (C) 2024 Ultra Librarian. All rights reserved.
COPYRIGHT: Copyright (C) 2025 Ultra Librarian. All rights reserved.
